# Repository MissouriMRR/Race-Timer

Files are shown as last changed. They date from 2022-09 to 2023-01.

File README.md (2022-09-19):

# Overview

This repository contains the PCB files for the PIDFlight Lap PCB files and CAD files.

# Features

-Using the PIDFlight software these timers can
  -Connect to an external device running the Software via bluetooth
  -keep track of multiple drones, using physical and digital timers

#### Physical

- Expected Size: 150mm x 150mm
- Rectangular shape
- Screw Mounting Holes 

#### Primary Components

- Arduino Nano x4
- RX5808 x4
- HC_06 x4
- 1k Ohm resistors x12

#### Power

- Connection to LiPo Packs
- switch spot to remove power when not in use

# Companion Documentation

RX5808 Datasheet: https://www.foxtechfpv.com/product/5.8G%20modules/rx5808/RX5808-Spec-V1.pdf 

HC_06 Bluetooth Module Datasheet: https://components101.com/wireless/hc-06-bluetooth-module-pinout-datasheet

PIDFlight Lap Website: https://www.pidflight.com/pidflight-lap/rev02/

   -Schematic from website: file:///C:/Users/c0nn0/Downloads/PIDflight-Lap-Timing-Schematic-Revision-01.pdf
      
   -Communication Wiring Diagram from website: https://www.pidflight.com/pidflight-lap/multipilot/

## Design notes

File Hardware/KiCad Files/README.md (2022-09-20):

The PIDFlight lap is the PCB files the other folders are for component footprints and symbols

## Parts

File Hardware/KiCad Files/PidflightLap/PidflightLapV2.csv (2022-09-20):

Source: | C:\Users\c0nn0\Documents\Drone\PidflightLap\PidflightLapV2.kicad_sch
Date: | 9/15/2022 8:03:05 PM
Tool: | Eeschema (6.0.7)
Generator: | C:\Program Files\KiCad\6.0\bin\scripting\plugins/bom_csv_grouped_by_value.py
Component Count: | 27
Individual Components:
Item | Qty | Reference(s) | Value | LibPart | Footprint | Datasheet
 |  | 1k1 | R1 | Device:R | Resistor_THT:R_Axial_DIN0204_L3.6mm_D1.6mm_P7.62mm_Horizontal | ~
 |  | 1k2 | R2 | Device:R | Resistor_THT:R_Axial_DIN0204_L3.6mm_D1.6mm_P7.62mm_Horizontal | ~
 |  | 1k3 | R3 | Device:R | Resistor_THT:R_Axial_DIN0204_L3.6mm_D1.6mm_P7.62mm_Horizontal | ~
 |  | 1k4 | R4 | Device:R | Resistor_THT:R_Axial_DIN0204_L3.6mm_D1.6mm_P7.62mm_Horizontal | ~
 |  | 1k5 | R5 | Device:R | Resistor_THT:R_Axial_DIN0204_L3.6mm_D1.6mm_P7.62mm_Horizontal | ~
 |  | 1k6 | R6 | Device:R | Resistor_THT:R_Axial_DIN0204_L3.6mm_D1.6mm_P7.62mm_Horizontal | ~
 |  | 1k7 | R7 | Device:R | Resistor_THT:R_Axial_DIN0204_L3.6mm_D1.6mm_P7.62mm_Horizontal | ~
 |  | 1k8 | R8 | Device:R | Resistor_THT:R_Axial_DIN0204_L3.6mm_D1.6mm_P7.62mm_Horizontal | ~
 |  | 1k9 | R9 | Device:R | Resistor_THT:R_Axial_DIN0204_L3.6mm_D1.6mm_P7.62mm_Horizontal | ~
 |  | 1k10 | R10 | Device:R | Resistor_THT:R_Axial_DIN0204_L3.6mm_D1.6mm_P7.62mm_Horizontal | ~
 |  | 1k11 | R11 | Device:R | Resistor_THT:R_Axial_DIN0204_L3.6mm_D1.6mm_P7.62mm_Horizontal | ~
 |  | 1k12 | R12 | Device:R | Resistor_THT:R_Axial_DIN0204_L3.6mm_D1.6mm_P7.62mm_Horizontal | ~
 |  | B1 | Buzzer | MRDT_Devices:Buzzer | Buzzer_Beeper:Buzzer_12x9.5RM7.6
 |  | B2 | Buzzer | MRDT_Devices:Buzzer | Buzzer_Beeper:Buzzer_12x9.5RM7.6
 |  | B3 | Buzzer | MRDT_Devices:Buzzer | Buzzer_Beeper:Buzzer_12x9.5RM7.6
 |  | B4 | Buzzer | MRDT_Devices:Buzzer | Buzzer_Beeper:Buzzer_12x9.5RM7.6
 |  | BT1 | Battery | Device:Battery | ArduinoNanoV3 - Copy:SMD Solder Pads | ~
 |  | SW1 | SW_SPST | Switch:SW_SPST | ArduinoNanoV3 - Copy:SMD Solder Pads | ~
 |  | U1 | HC_06 | HC_06:HC_06 | HC_06:HC_06 Bluetooth Module
 |  | U2 | RX5808 | :RX5808_1 | RX5808 Footprint:RX5808
 |  | U3 | Arduino_Nano_v3.x | MCU_Module:Arduino_Nano_v3.x | ArduinoNanoV3 - Copy:SHIELD_ARDUINO_NANO | http://www.mouser.com/pdfdocs/Gravitech_Arduino_Nano3_0.pdf
 |  | U4 | RX5808 | RX5808:RX5808 | RX5808 Footprint:RX5808
 |  | U5 | Arduino_Nano_v3.x | MCU_Module:Arduino_Nano_v3.x | ArduinoNanoV3 - Copy:SHIELD_ARDUINO_NANO | http://www.mouser.com/pdfdocs/Gravitech_Arduino_Nano3_0.pdf
 |  | U6 | RX5808 | RX5808:RX5808 | RX5808 Footprint:RX5808
 |  | U7 | Arduino_Nano_v3.x | MCU_Module:Arduino_Nano_v3.x | ArduinoNanoV3 - Copy:SHIELD_ARDUINO_NANO | http://www.mouser.com/pdfdocs/Gravitech_Arduino_Nano3_0.pdf
 |  | U8 | RX5808 | RX5808:RX5808 | RX5808 Footprint:RX5808
 |  | U9 | Arduino_Nano_v3.x | MCU_Module:Arduino_Nano_v3.x | ArduinoNanoV3 - Copy:SHIELD_ARDUINO_NANO | http://www.mouser.com/pdfdocs/Gravitech_Arduino_Nano3_0.pdf
Collated Components:
Item | Qty | Reference(s) | Value | LibPart | Footprint | Datasheet
1 | 1 | 1k1 | R1 | Device:R | Resistor_THT:R_Axial_DIN0204_L3.6mm_D1.6mm_P7.62mm_Horizontal | ~
2 | 1 | 1k2 | R2 | Device:R | Resistor_THT:R_Axial_DIN0204_L3.6mm_D1.6mm_P7.62mm_Horizontal | ~
3 | 1 | 1k3 | R3 | Device:R | Resistor_THT:R_Axial_DIN0204_L3.6mm_D1.6mm_P7.62mm_Horizontal | ~
4 | 1 | 1k4 | R4 | Device:R | Resistor_THT:R_Axial_DIN0204_L3.6mm_D1.6mm_P7.62mm_Horizontal | ~
5 | 1 | 1k5 | R5 | Device:R | Resistor_THT:R_Axial_DIN0204_L3.6mm_D1.6mm_P7.62mm_Horizontal | ~
6 | 1 | 1k6 | R6 | Device:R | Resistor_THT:R_Axial_DIN0204_L3.6mm_D1.6mm_P7.62mm_Horizontal | ~
7 | 1 | 1k7 | R7 | Device:R | Resistor_THT:R_Axial_DIN0204_L3.6mm_D1.6mm_P7.62mm_Horizontal | ~
8 | 1 | 1k8 | R8 | Device:R | Resistor_THT:R_Axial_DIN0204_L3.6mm_D1.6mm_P7.62mm_Horizontal | ~
9 | 1 | 1k9 | R9 | Device:R | Resistor_THT:R_Axial_DIN0204_L3.6mm_D1.6mm_P7.62mm_Horizontal | ~
10 | 1 | 1k10 | R10 | Device:R | Resistor_THT:R_Axial_DIN0204_L3.6mm_D1.6mm_P7.62mm_Horizontal | ~
11 | 1 | 1k11 | R11 | Device:R | Resistor_THT:R_Axial_DIN0204_L3.6mm_D1.6mm_P7.62mm_Horizontal | ~
12 | 1 | 1k12 | R12 | Device:R | Resistor_THT:R_Axial_DIN0204_L3.6mm_D1.6mm_P7.62mm_Horizontal | ~
13 | 4 | B1, B2, B3, B4 | Buzzer | MRDT_Devices:Buzzer | Buzzer_Beeper:Buzzer_12x9.5RM7.6
14 | 1 | BT1 | Battery | Device:Battery | ArduinoNanoV3 - Copy:SMD Solder Pads | ~
15 | 1 | SW1 | SW_SPST | Switch:SW_SPST | ArduinoNanoV3 - Copy:SMD Solder Pads | ~
16 | 1 | U1 | HC_06 | HC_06:HC_06 | HC_06:HC_06 Bluetooth Module
17 | 1 | U2 | RX5808 | :RX5808_1 | RX5808 Footprint:RX5808
18 | 4 | U3, U5, U7, U9 | Arduino_Nano_v3.x | MCU_Module:Arduino_Nano_v3.x | ArduinoNanoV3 - Copy:SHIELD_ARDUINO_NANO | http://www.mouser.com/pdfdocs/Gravitech_Arduino_Nano3_0.pdf
19 | 3 | U4, U6, U8 | RX5808 | RX5808:RX5808 | RX5808 Footprint:RX5808

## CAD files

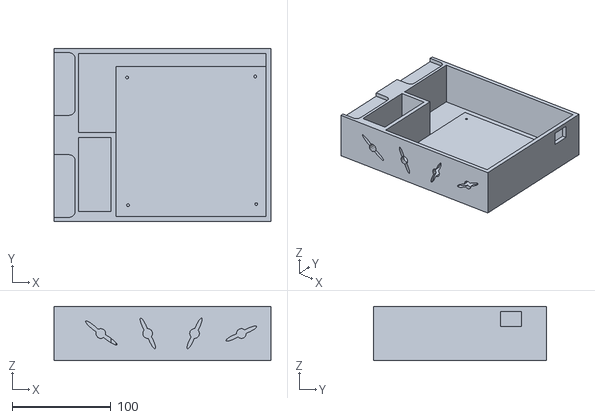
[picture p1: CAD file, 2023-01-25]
PCB Box v3.stl
220.0 x 175.0 x 55.0

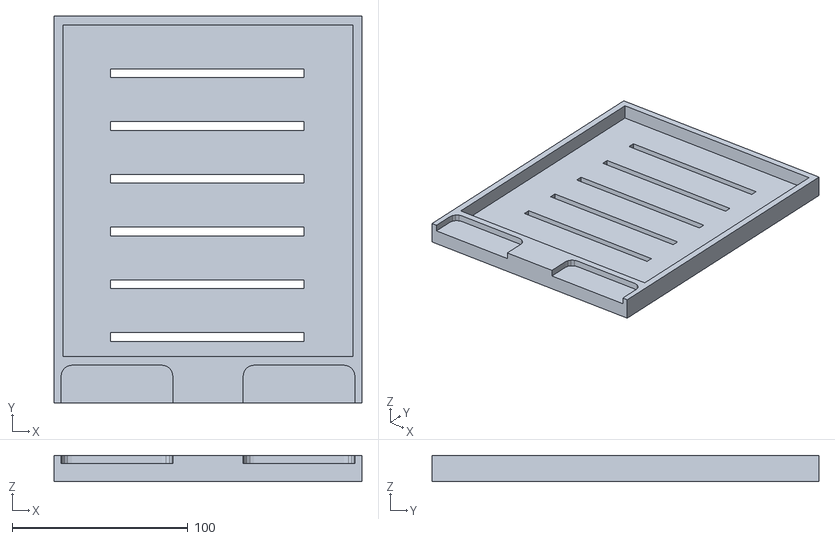
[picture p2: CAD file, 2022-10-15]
PCB Lid v3.stl
175.0 x 220.0 x 15.0

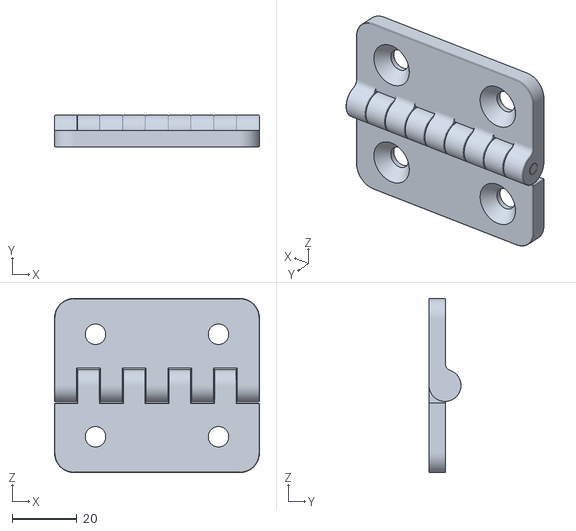
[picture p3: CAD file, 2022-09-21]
PCB Door Hinge V1.stl
63.5 x 9.90 x 54.0

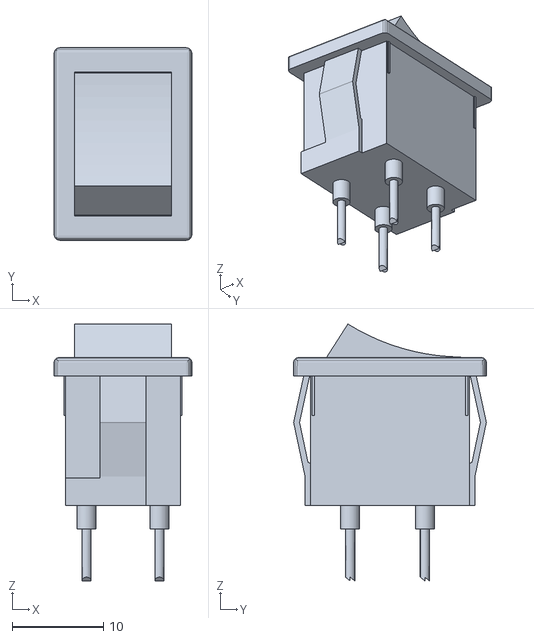
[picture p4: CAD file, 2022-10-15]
7395K712_Rocker Switch.stl
15.1 x 21.1 x 28.1

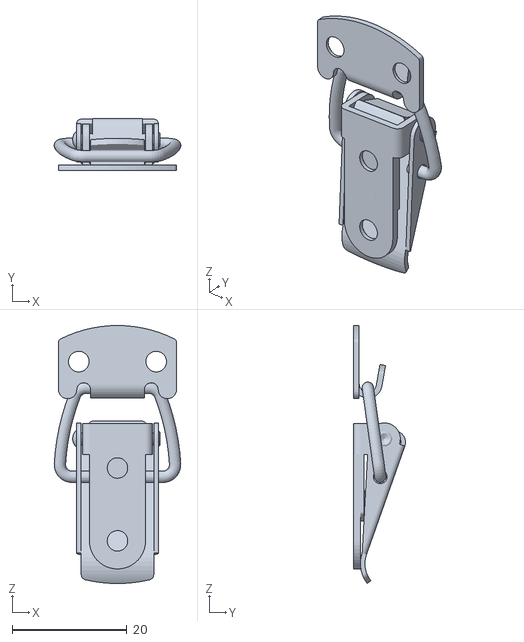
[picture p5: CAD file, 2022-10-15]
6082A12_Draw Latch.stl
22.1 x 9.08 x 45.0

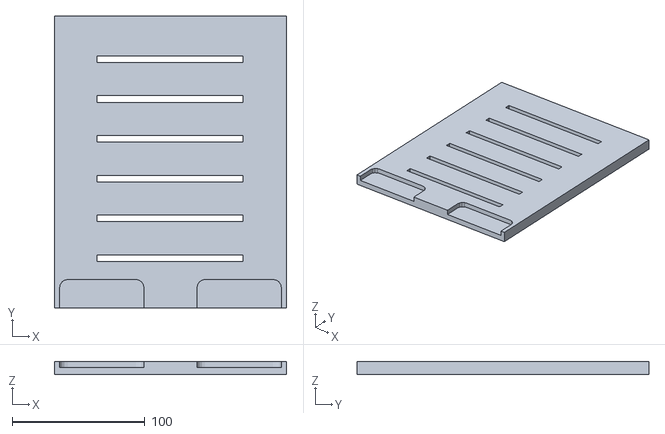
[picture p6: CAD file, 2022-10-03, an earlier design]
PCB Lid v2.stl
175.0 x 220.0 x 10.0

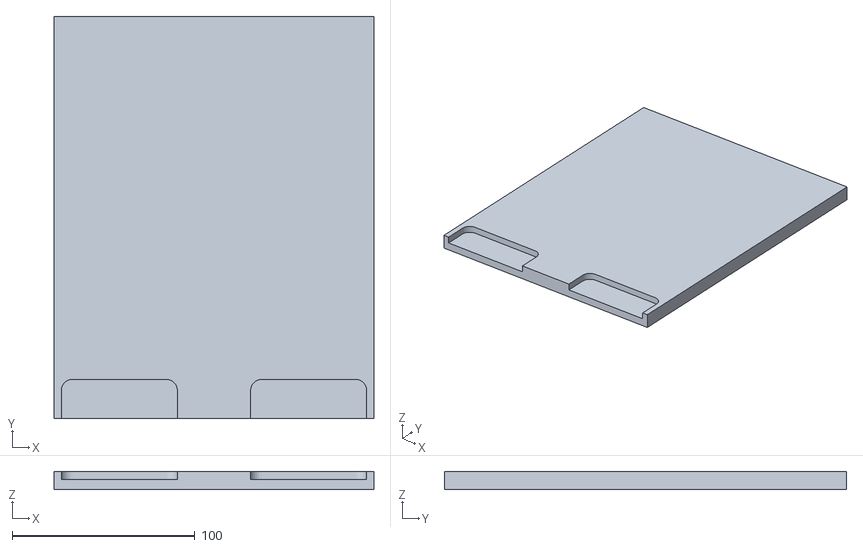
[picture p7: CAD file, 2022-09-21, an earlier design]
PCB Lid - V1.stl
175.0 x 220.0 x 10.0

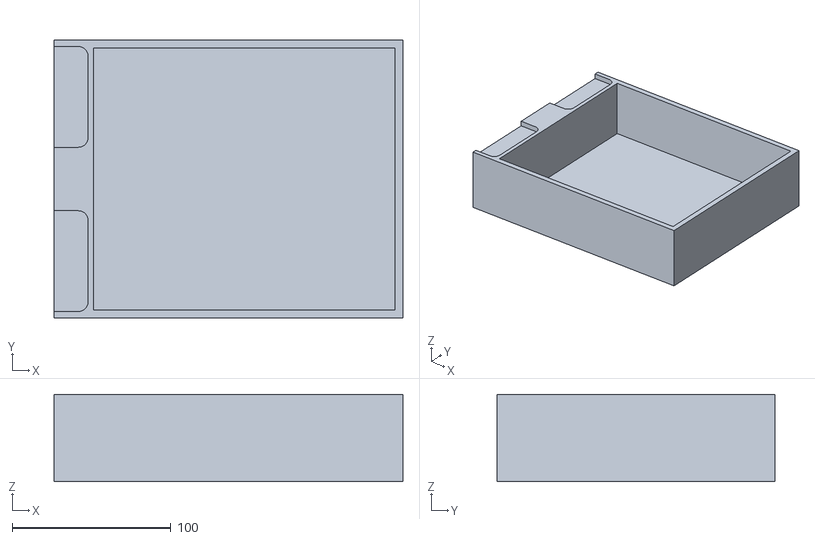
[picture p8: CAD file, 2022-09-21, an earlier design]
PCB Box V1.stl
220.0 x 175.0 x 55.0

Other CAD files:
PCB Box v2.stl
PCB Box v3.ipt

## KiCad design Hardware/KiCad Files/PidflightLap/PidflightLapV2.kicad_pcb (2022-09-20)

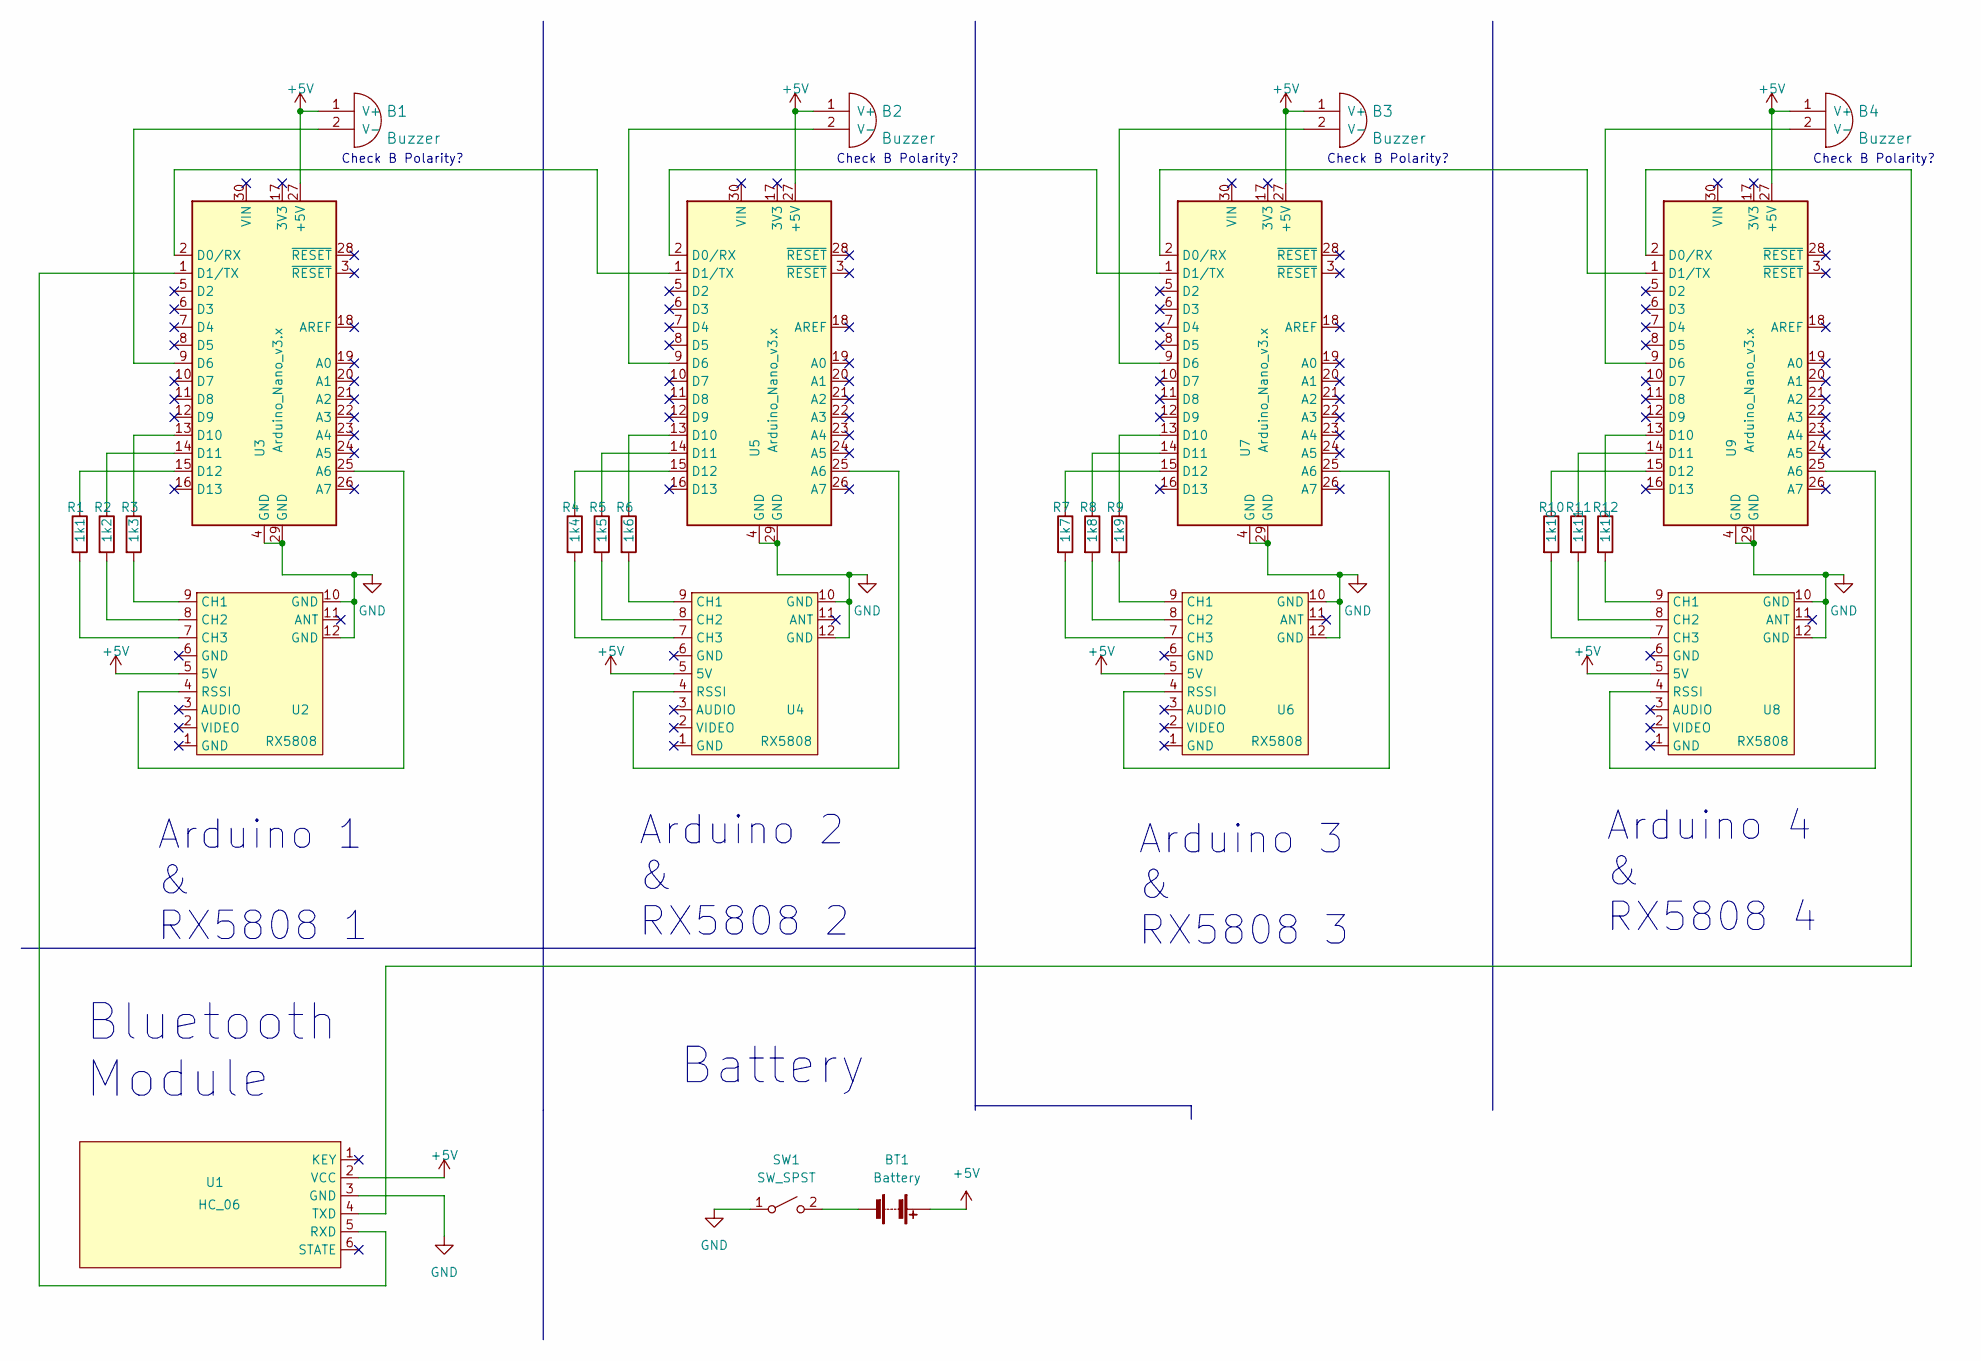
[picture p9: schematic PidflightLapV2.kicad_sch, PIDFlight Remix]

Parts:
1k1: R1; R_Axial_DIN0204_L3.6mm_D1.6mm_P7.62mm_Horizontal
1k2: R2; R_Axial_DIN0204_L3.6mm_D1.6mm_P7.62mm_Horizontal
1k3: R3; R_Axial_DIN0204_L3.6mm_D1.6mm_P7.62mm_Horizontal
1k4: R4; R_Axial_DIN0204_L3.6mm_D1.6mm_P7.62mm_Horizontal
1k5: R5; R_Axial_DIN0204_L3.6mm_D1.6mm_P7.62mm_Horizontal
1k6: R6; R_Axial_DIN0204_L3.6mm_D1.6mm_P7.62mm_Horizontal
1k7: R7; R_Axial_DIN0204_L3.6mm_D1.6mm_P7.62mm_Horizontal
1k8: R8; R_Axial_DIN0204_L3.6mm_D1.6mm_P7.62mm_Horizontal
1k9: R9; R_Axial_DIN0204_L3.6mm_D1.6mm_P7.62mm_Horizontal
1k10: R10; R_Axial_DIN0204_L3.6mm_D1.6mm_P7.62mm_Horizontal
1k11: R11; R_Axial_DIN0204_L3.6mm_D1.6mm_P7.62mm_Horizontal
1k12: R12; R_Axial_DIN0204_L3.6mm_D1.6mm_P7.62mm_Horizontal
B1, B2, B3, B4: Buzzer; Buzzer_12x9.5RM7.6
BT1: Battery; TerminalBlock_Altech_AK300-2_P5.00mm
SW1: SW_SPST; SMD Solder Pads
U1: HC_06; HC_06 Bluetooth Module
U2, U4, U6, U8: RX5808
U3, U5, U7, U9: Arduino_Nano_v3.x; Arduino_Nano

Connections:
+5V: B1.1 (V+), B2.1 (V+), B3.1 (V+), B4.1 (V+), BT1.1 (+), U1.2 (VCC), U2.5 (5V), U3.27 (+5V), U4.5 (5V), U5.27 (+5V), U6.5 (5V), U7.27 (+5V), U8.5 (5V), U9.27 (+5V)
GND: SW1.1 (A), U1.3 (GND), U2.10 (GND), U2.12 (GND), U3.4 (GND), U3.29 (GND), U4.10 (GND), U4.12 (GND), U5.4 (GND), U5.29 (GND), U6.10 (GND), U6.12 (GND), U7.4 (GND), U7.29 (GND), U8.10 (GND), U8.12 (GND), U9.4 (GND), U9.29 (GND)
unnamed: 1k1.1, U3.15 (D12)
unnamed: 1k1.2, U2.7 (CH3)
unnamed: 1k2.1, U3.14 (D11)
unnamed: 1k2.2, U2.8 (CH2)
unnamed: 1k3.1, U3.13 (D10)
unnamed: 1k3.2, U2.9 (CH1)
unnamed: 1k4.1, U5.15 (D12)
unnamed: 1k4.2, U4.7 (CH3)
unnamed: 1k5.1, U5.14 (D11)
unnamed: 1k5.2, U4.8 (CH2)
unnamed: 1k6.1, U5.13 (D10)
unnamed: 1k6.2, U4.9 (CH1)
unnamed: 1k7.1, U7.15 (D12)
unnamed: 1k7.2, U6.7 (CH3)
unnamed: 1k8.1, U7.14 (D11)
unnamed: 1k8.2, U6.8 (CH2)
unnamed: 1k9.1, U7.13 (D10)
unnamed: 1k9.2, U6.9 (CH1)
unnamed: 1k10.1, U9.15 (D12)
unnamed: 1k10.2, U8.7 (CH3)
unnamed: 1k11.1, U9.14 (D11)
unnamed: 1k11.2, U8.8 (CH2)
unnamed: 1k12.1, U9.13 (D10)
unnamed: 1k12.2, U8.9 (CH1)
unnamed: B1.2 (V-), U3.9 (D6)
unnamed: B2.2 (V-), U5.9 (D6)
unnamed: B3.2 (V-), U7.9 (D6)
unnamed: B4.2 (V-), U9.9 (D6)
unnamed: BT1.2 (-), SW1.2 (B)
unnamed: U1.4 (TXD), U9.2 (D0/RX)
unnamed: U1.5 (RXD), U3.1 (D1/TX)
unnamed: U2.4 (RSSI), U3.25 (A6)
unnamed: U3.2 (D0/RX), U5.1 (D1/TX)
unnamed: U4.4 (RSSI), U5.25 (A6)
unnamed: U5.2 (D0/RX), U7.1 (D1/TX)
unnamed: U6.4 (RSSI), U7.25 (A6)
unnamed: U7.2 (D0/RX), U9.1 (D1/TX)
unnamed: U8.4 (RSSI), U9.25 (A6)

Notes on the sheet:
Arduino 4 & RX5808 4
Check B Polarity?
Bluetooth Module
Arduino 2 & RX5808 2
Arduino 1 & RX5808 1
Arduino 3 & RX5808 3
Battery

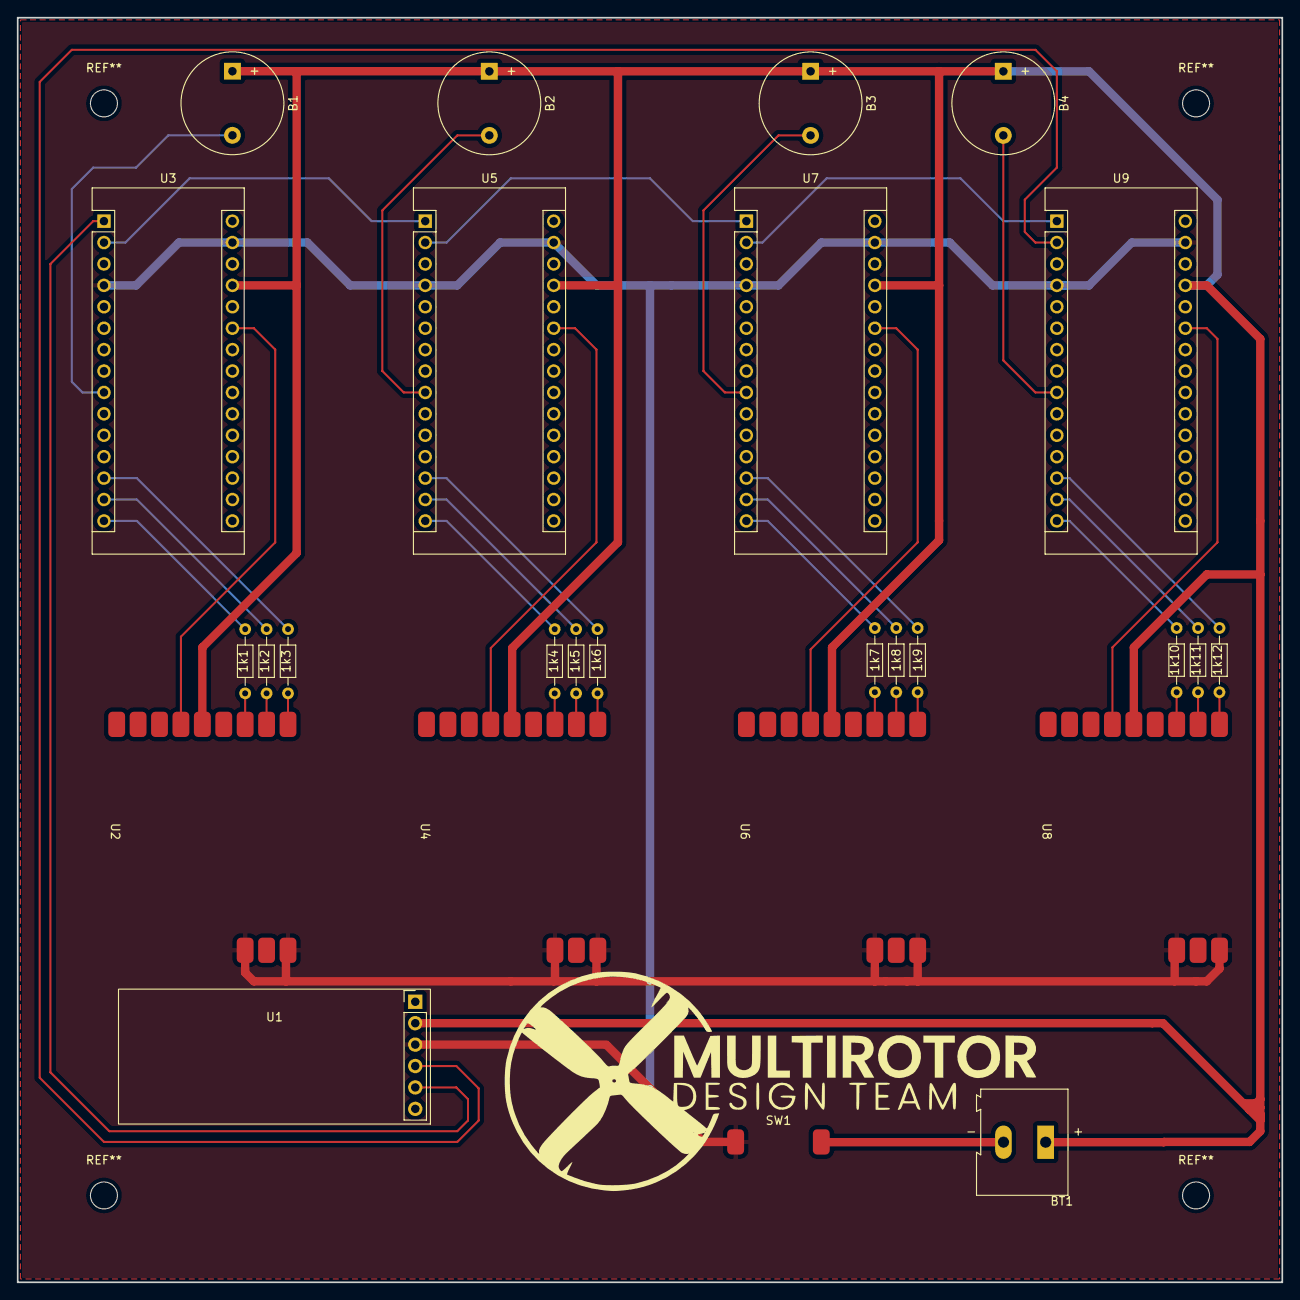
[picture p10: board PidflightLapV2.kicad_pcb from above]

Board: 2 copper layers, 150.0 x 150.0 mm, 28 parts (0 on the bottom side), 40 nets.

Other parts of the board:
G: LOGO; multirotorwordsfootprint

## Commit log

2022-09-19 Updated README
    Fixed the readme to contain relevent information to the board and the PIDFlight project.
2022-09-20 Added KiCAD Files
    [PidflightLap.kicad_pcb, PidflightLap.kicad_sch, PidflightLapV2.csv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]
2022-10-01 Add files via upload
    Version 2 with every added feature. (Needs to be changed upon request for certain sizing requirements)
    [PCB Box v2.stl, PCB Lid v2.stl]
2022-10-15 Version 3 of PCB Box Design
    Some more slight changes to the PCB Box design. I also added the locking cad file as well as a cad file for a switch.
    [6082A12_Draw Latch.stl, 7395K712_Rocker Switch.stl, PCB Box v3.stl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]
2023-01-25 Add files via upload
    This version has an updated text font that won't look wacky.
    [PCB Box v3.ipt]
2023-01-25 Updated Font That Don't Look Wack
    [PCB Box v3.stl]
